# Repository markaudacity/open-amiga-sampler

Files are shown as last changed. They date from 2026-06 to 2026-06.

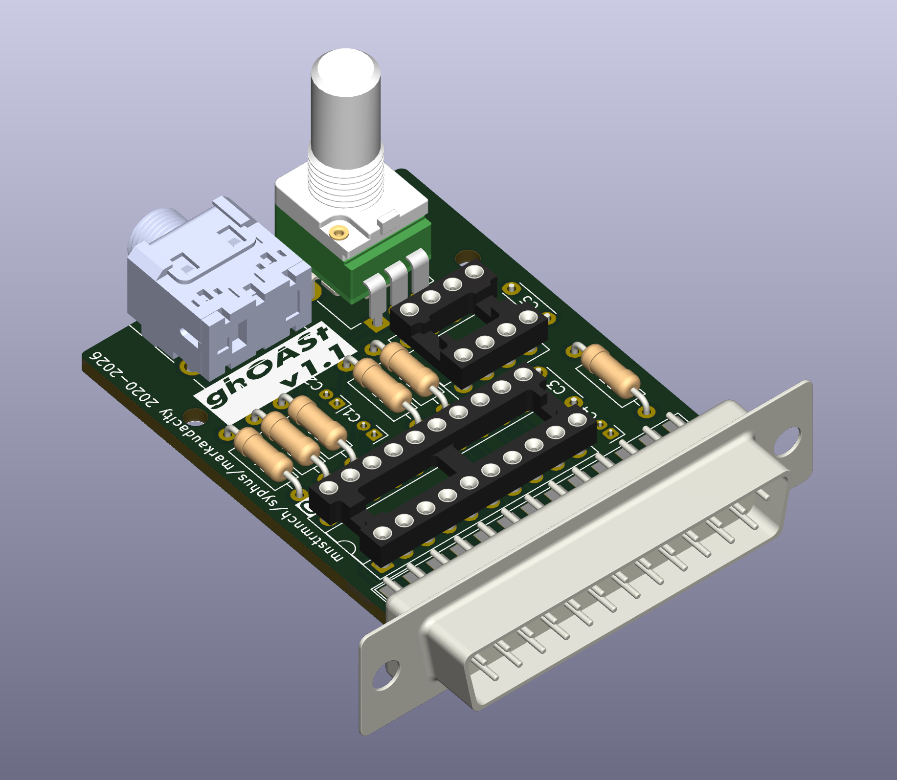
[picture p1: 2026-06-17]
img/ghOASt_v1.1_ortho.png

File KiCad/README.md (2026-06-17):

# OPEN AMIGA SAMPLER

## Overview

Here you can find the schematic and a PCB layout for Open Amiga Sampler in KiCAD format. Additionally, the schematic is available as a PDF.
The design consists of an inverting opamp circuit with variable gain which feeds an ADC. The DB25's strobe pin is connected to the ADC and initiates a conversion when it goes low. The ADC's outputs are connected to the data pins of a DB25 connector, which also provides power and ground. 

## BOM

* 1x Maxim ADC0820CCN+
* 1x Microchip MCP6002-I/P
* 1x DB25 plug connector
* 2x RCA receptacles
* 1x 330ohm resistor
* 5x 1kohm resistors
* 1x 10kohm exponential potentimeter
* 1x 47uf capacitor
* 2x 10uf capacitors
* 2x 0.1uf capacitors

### Substitutions

The 10kohm potentiometer will give between 1x and 10x gain. A larger potentiometer can be substituted to enable a large maxium gain. The RCA receptacles can be replaced by a stereo jack receptacle if preferred. It is likely that both ICs could be substituted for similar chips with identical pinouts, but these are the models that we have tested and confirmed to work.

## Soldering

All components are through-hole and should be relatively easy to solder even for a novice. Some components can be soldered to the back of the board and folded down to make the overall unit slimmer. One possible configuration is to solder C1, C2, C3 and C5 to the back of the board, and fold C4 down onto the front footprint of C3. We recommend soldering the DB25 connector first, followed by the passive components and leads, and finally the ICs. This reduces the chance of damaging the ICs with excessive heat.

## Case

We are working on a compact 3D printed case in an approriate form factor for all Amiga computers. You may be able to find an appropriate enclosure to build the device into, but if you intend to plug the device directly into your Amiga you will need to make sure that ports adjacent to the parallel port will not be impeded.

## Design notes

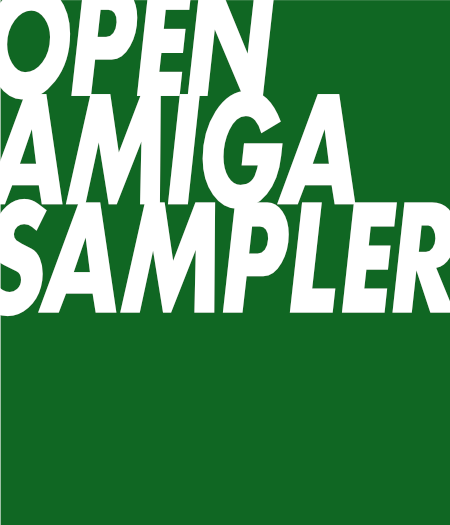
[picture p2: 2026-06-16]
graphics/open amiga sampler interrupted styletext.png

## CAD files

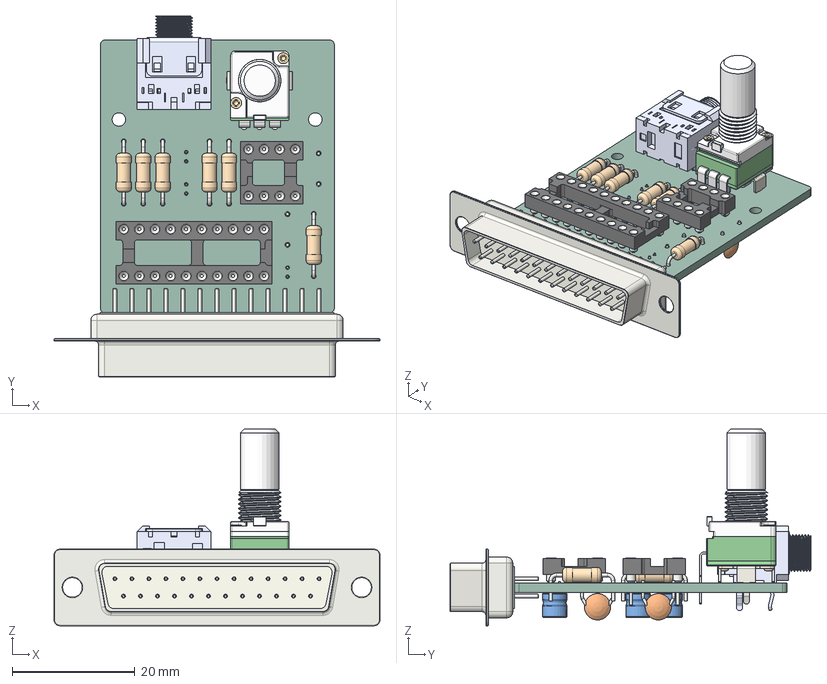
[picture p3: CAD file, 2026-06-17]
KiCad/ghOASt v1.1.step
53.1 x 58.7 x 32.0 mm
DSUB-25_Male_Vertical_P2.77x2.84mm
DIP_20_W762mm_Socket
R_Axial_DIN0207_L63mm_D25mm_P1016mm_Horizontal x 6
DIP_8_W762mm_Socket
CUI_DEVICES_SJ1-3543
RD901F-40-15R1 v9
CP_Radial_D40mm_P150mm x 3
C_Disc_D43mm_W19mm_P500mm x 2
open-amiga-sampler_PCB

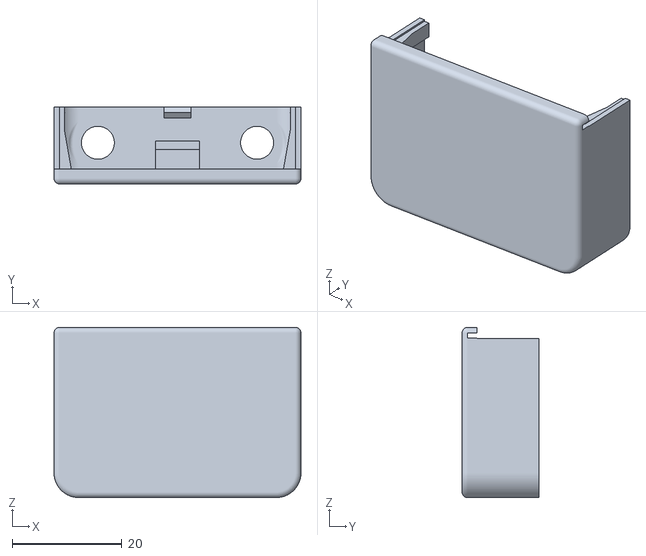
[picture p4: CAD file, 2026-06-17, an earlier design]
legacy/smd-fork/case models/OAS-lower-shell.stl
45.0 x 14.0 x 31.0

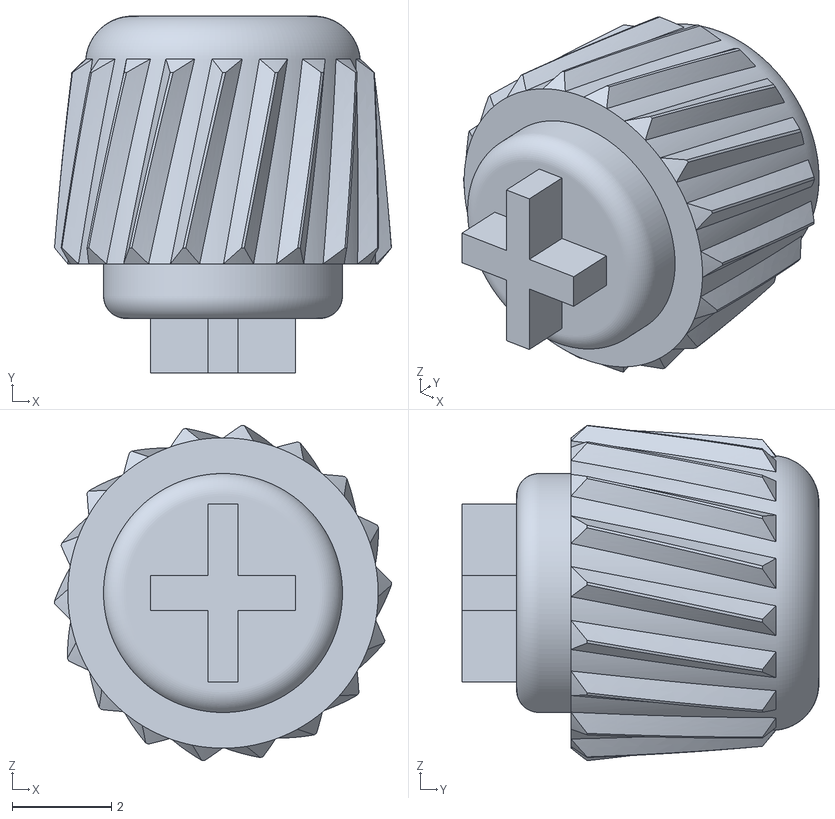
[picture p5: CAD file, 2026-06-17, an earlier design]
legacy/smd-fork/case models/OAS-trimmer-knob.stl
6.80 x 7.20 x 6.77

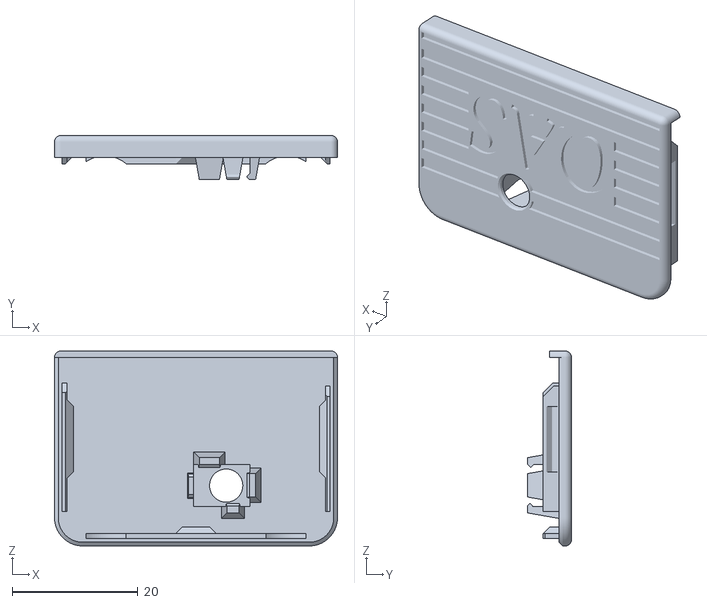
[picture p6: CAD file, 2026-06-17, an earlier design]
legacy/smd-fork/case models/OAS-Top shell.stl
45.0 x 7.00 x 31.0

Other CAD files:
graphics/open amiga sampler interrupted styletext.dxf
graphics/open amiga sampler interrupted styletext.dwg

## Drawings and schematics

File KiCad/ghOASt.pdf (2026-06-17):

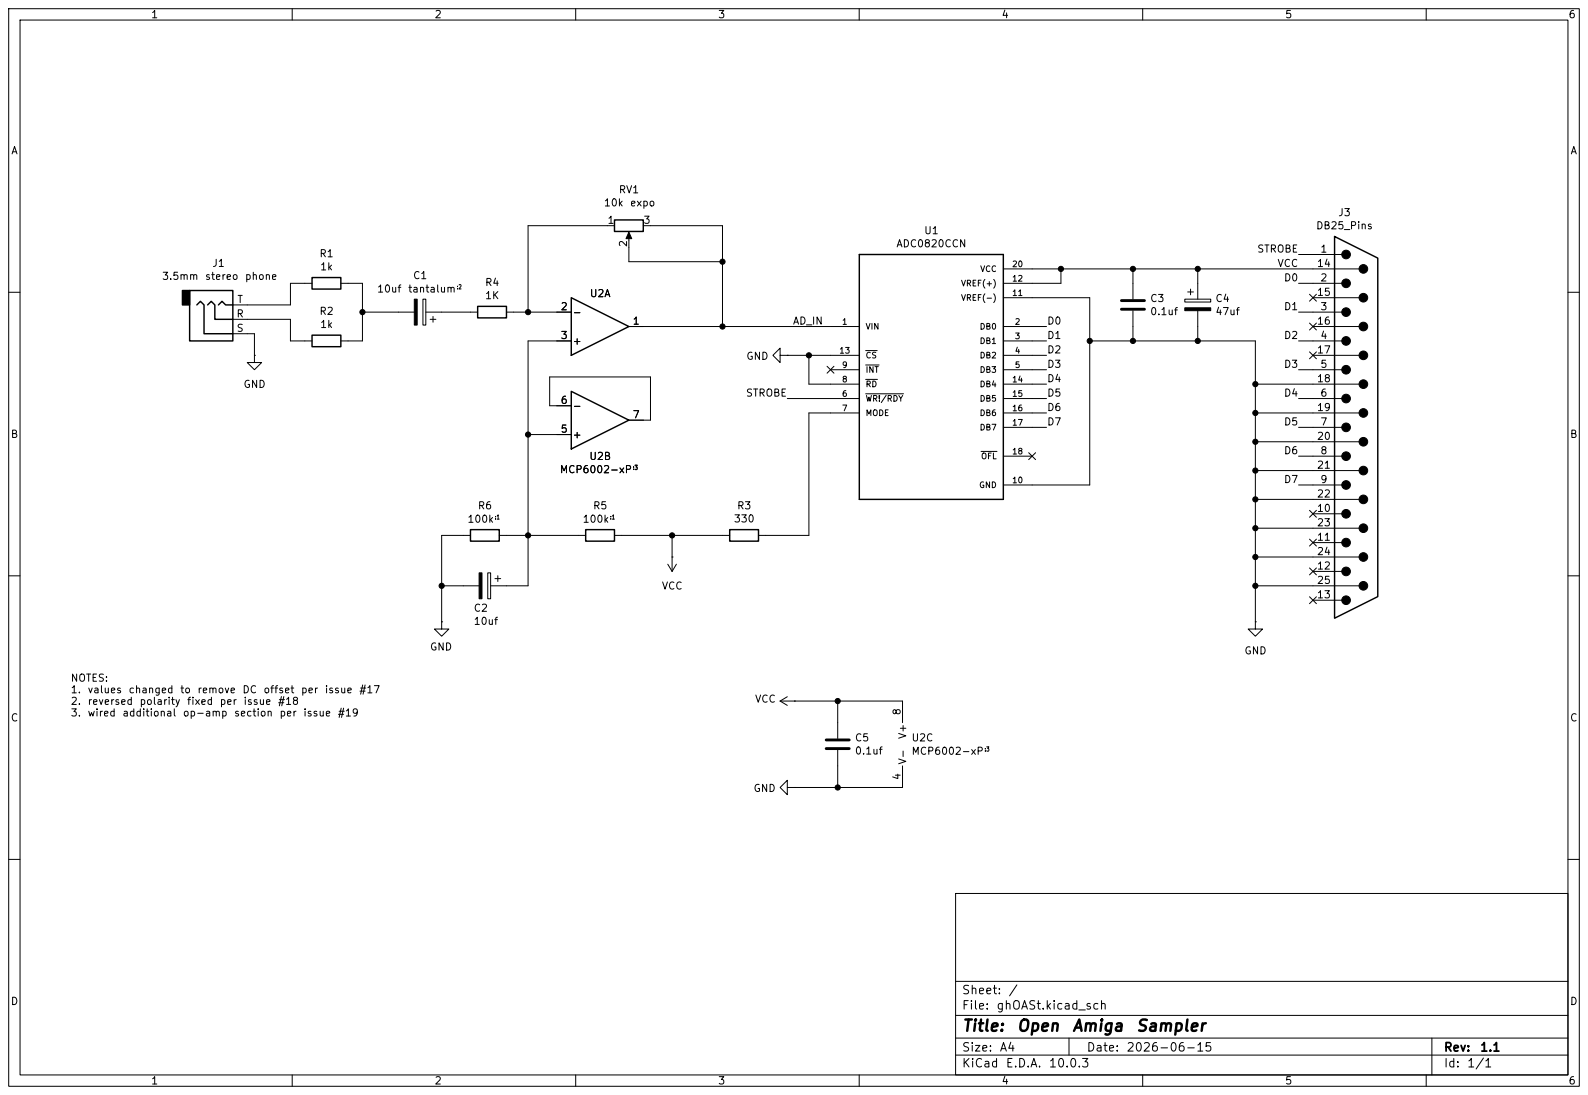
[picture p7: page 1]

STROBED0 NOTES: 1. values changed to remove DC offset per issue #17

2. reversed polarity fixed per issue #18

Sheet: /
File: ghOASt.kicad_sch
Title: Open Amiga Sampler

Size: A4 | Rev: 1.1
KiCad E.D.A. 10.0.3 | Id: 1/1

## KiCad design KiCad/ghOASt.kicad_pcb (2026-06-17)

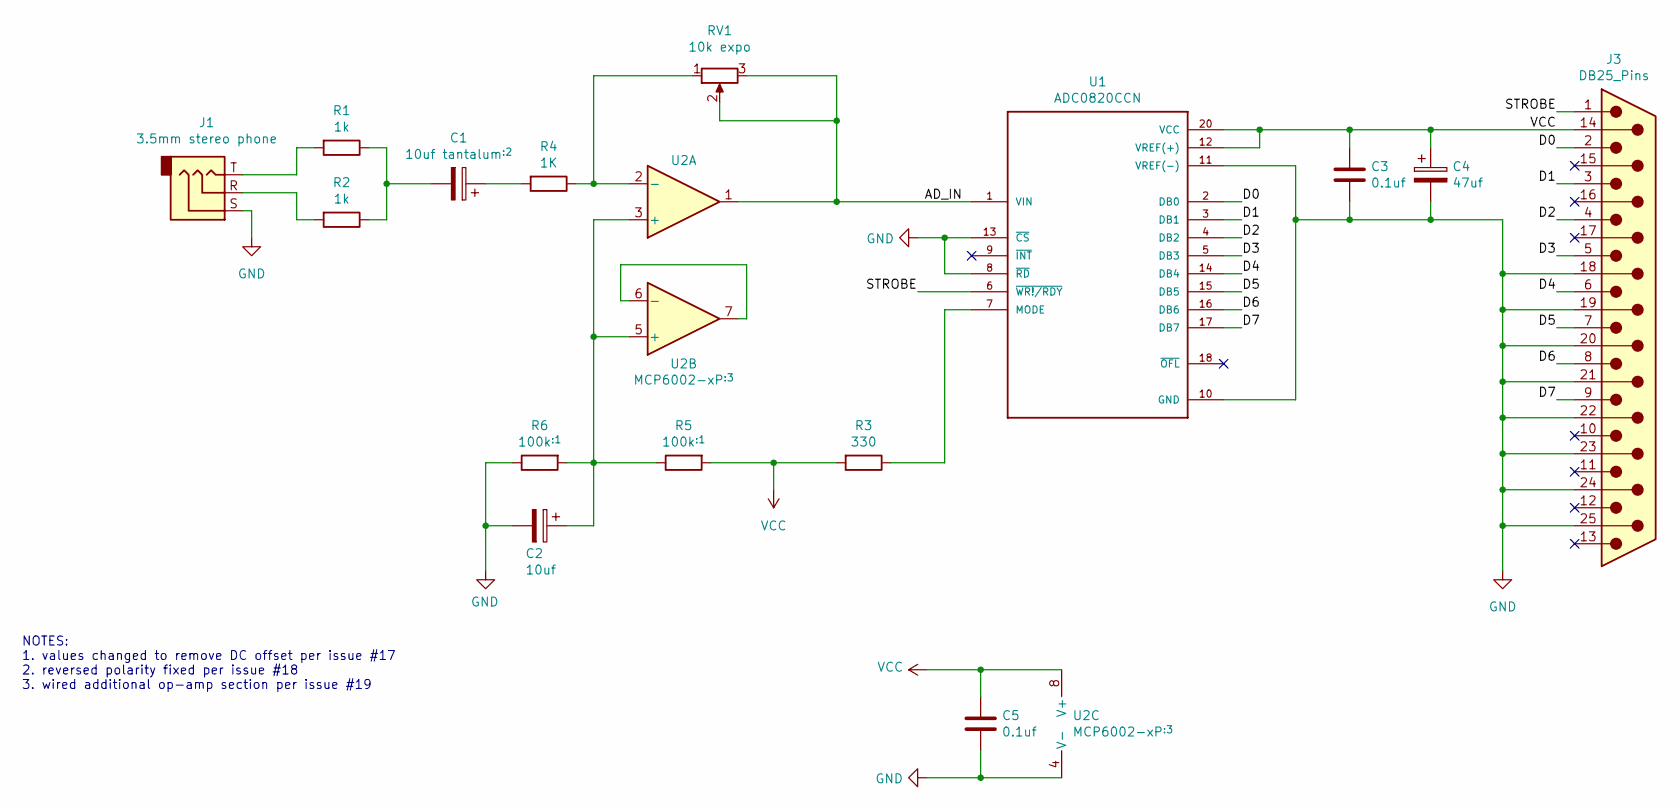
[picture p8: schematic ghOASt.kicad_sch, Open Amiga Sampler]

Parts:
C1: 10uf tantalum^{:2}; CP_Radial_D4.0mm_P1.50mm
C2: 10uf; CP_Radial_D4.0mm_P1.50mm
C3, C5: 0.1uf; C_Disc_D4.3mm_W1.9mm_P5.00mm
C4: 47uf; CP_Radial_D4.0mm_P1.50mm
J1: 3.5mm stereo phone; Jack_3.5mm_CUI_SJ1-3543
J3: DB25_Pins; DSUB-25_Male_EdgeMount_P2.77mm
R1, R2: 1k; R_Axial_DIN0207_L6.3mm_D2.5mm_P10.16mm_Horizontal
R3: 330; R_Axial_DIN0207_L6.3mm_D2.5mm_P10.16mm_Horizontal
R4: 1K; R_Axial_DIN0207_L6.3mm_D2.5mm_P10.16mm_Horizontal
R5, R6: 100k^{:1}; R_Axial_DIN0207_L6.3mm_D2.5mm_P10.16mm_Horizontal
RV1: 10k expo; Potentiometer_Alpha_RD901F-40-00D_Single_Vertical
U1: ADC0820CCN; DIP-20_W7.62mm_Socket
U2: MCP6002-xP^{:3}; DIP-8_W7.62mm_Socket

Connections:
/AD_IN: RV1.2, RV1.3, U1.1 (VIN), U2.1
/D0: J3.2, U1.2 (DB0)
/D1: J3.3, U1.3 (DB1)
/D2: J3.4, U1.4 (DB2)
/D3: J3.5, U1.5 (DB3)
/D4: J3.6, U1.14 (DB4)
/D5: J3.7, U1.15 (DB5)
/D6: J3.8, U1.16 (DB6)
/D7: J3.9, U1.17 (DB7)
/STROBE: J3.1, U1.6 (~WR!/RDY)
GND: C2.2, C3.2, C4.2, C5.2, J1.S, J3.18, J3.19, J3.20, J3.21, J3.22, J3.23, J3.24, J3.25, R6.1, U1.8 (~RD), U1.10 (GND), U1.11 (VREF(-)), U1.13 (~CS), U2.4 (V-)
unnamed: C1.1, R4.2
unnamed: C1.2, R1.1, R2.1
unnamed: J1.R, R2.2
unnamed: J1.T, R1.2
unnamed: R3.1, U1.7 (MODE)
unnamed: C2.1, R5.1, R6.2, U2.3 (+), U2.5 (+)
unnamed: R4.1, RV1.1, U2.2 (-)
unnamed: U2.6 (-), U2.7
VCC: C3.1, C4.1, C5.1, J3.14, R3.2, R5.2, U1.12 (VREF(+)), U1.20 (VCC), U2.8 (V+)

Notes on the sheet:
NOTES: 1. values changed to remove DC offset per issue #17 2. reversed polarity fixed per issue #18 3. wired additional op-amp section per issue #19

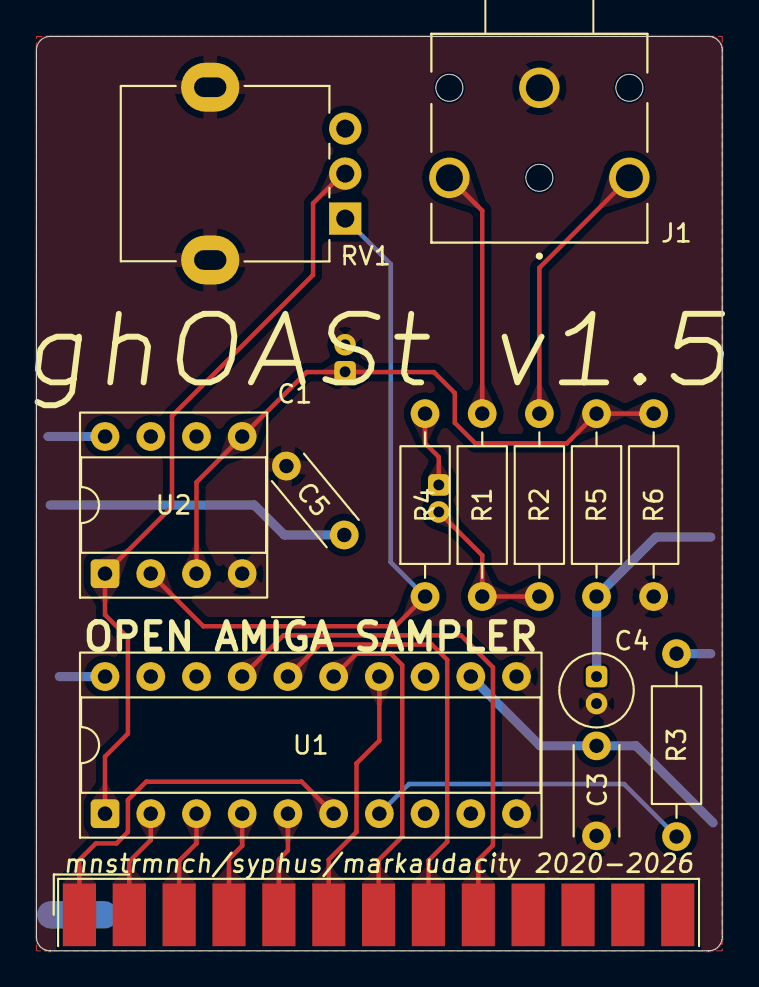
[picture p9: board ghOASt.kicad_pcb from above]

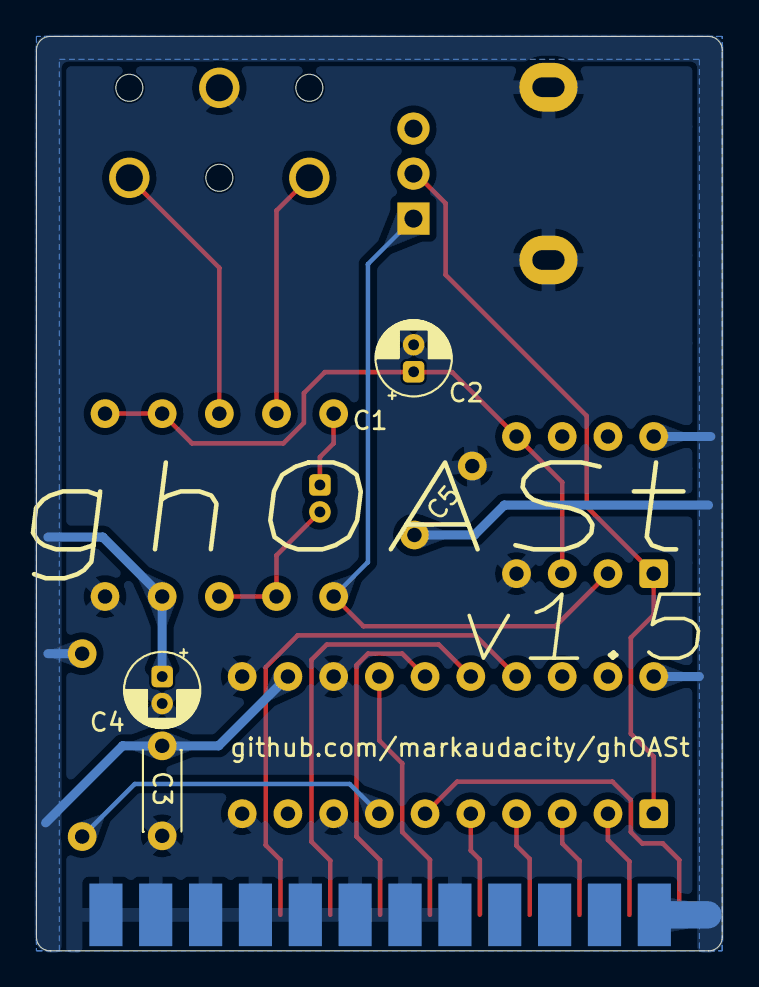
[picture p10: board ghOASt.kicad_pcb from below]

Board: 2 copper layers, 38.1 x 50.8 mm, 16 parts (5 on the bottom side), 20 nets.

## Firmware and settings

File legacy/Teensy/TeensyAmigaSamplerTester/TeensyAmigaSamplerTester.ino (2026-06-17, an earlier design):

/*
   http://github.com/echolevel/open-amiga-sampler
   
   Tested on Teensy 3.5 with microSD card
   USB type: 'Serial'
   CPU speed: '120Mhz'
   
   Everything else Arduino/Teensy default.
   
   This Teensy-based sampler tester mimics the behaviour of an Amiga parallel port during a 
   sampling operation (bytes are read and a a STROBE signal is emitted, as per the Amiga CIA 
   chip's behaviour). This is to reduce the risk of frying real Amigas' CIA chips during testing. 

   8 digital input pins connect straight to a DB25 connector's data pins, while three digital output pins 
   are converted from 3.3v to 5v before being connected to the DB25's STROBE, SELECT and PAPER_OUT pins.
   The DB25 connector also takes 5v directly from the Teensy's USB 5v input (this may need to be soldered 
   to the Teensy for a decent contact). See the OAS github for full docs/wiring diagrams.
   
   To convert raw: sox -t raw -r 16574.2757 -b 8 -c 1 -L -e signed-integer .\audio.raw .\audio.wav
   This tells sox to assume a samplerate that matches Protracker note C-3, and is calculated by 
   working out a PAL Amiga's clock speed divided by the note period from a LUT (214, in this case).
   -c is channel count 
   -L is endianness (irrelevant with 8bit values)
   -e is encoding, signed int

   Notes: the STROBE is sent by the Amiga's CIA chip at a fixed rate - ie the sample rate - after every
   data byte is read. On an Amiga this process is discrete/automatic, so from a programmer's perspective 
   the speed at which bytes are read (usually with an interrupt request - $DFF01E) is the desired sample 
   rate. But here we're doing it manually, sorta back to front. 

   The rate of that custom interrupt on the Amiga isn't actually the sample rate, it's the note period - 
   in other words, a value from a lookup table by which you divide the Amiga's PAL or NTSC clock frequency
   to get a sample rate. 

   5512.5 samplerate with 5 and 40 delays is roughly F-1 note

   Amiga clock: 3546895   
   B-3 period: 113
   F-1 period: 640

   B-3 samplerate: 31388.45
*/

#include <SPI.h>
#include <SD.h>
#include <SD_t3.h>

int strobePin = 9;
int paperPin = 10;
int selectPin = 11;
int speakerPin = 35;
int paperState = HIGH;
int selectState = LOW;

uint8_t inChar = 0;
int aBufferSize = 128000;
int bufferCount = 0;
int buffersWritten = 0;
uint8_t audioBuffer[128000];
const int chipSelect = BUILTIN_SDCARD;

// the setup routine runs once when you press reset:
void setup() {
    
  // 8 contiguous bits on Teensy 3.5:
  /*
     D0 2
     D1 14
     D2 7
     D3 8
     D4 6
     D5 20
     D6 21
     D7 5
  */
  pinMode(2, INPUT_PULLUP);
  pinMode(14, INPUT_PULLUP);
  pinMode(7, INPUT_PULLUP);
  pinMode(8, INPUT_PULLUP);
  pinMode(6, INPUT_PULLUP);
  pinMode(20, INPUT_PULLUP);
  pinMode(21, INPUT_PULLUP);
  pinMode(5, INPUT_PULLUP);  

  // These 3 control pins' logic output has to be converted to 5v 
  pinMode(strobePin, OUTPUT);
  // selectPin and paperPin control switching between left and right - tbc, but I think 
  // you alternate one high vs one low per read
  pinMode(selectPin, OUTPUT);
  pinMode(paperPin, OUTPUT);
  pinMode(speakerPin, OUTPUT);

  Serial.begin(9600);
  while (!Serial) {
    ; //wait for serial port to connect
  }


  Serial.print("Initialising SD card...");

  if (!SD.begin(chipSelect)) {
    Serial.println("Card failed, or not present");
    return;
  }
  Serial.println("card initialised");
  
}



// the loop routine runs over and over again forever:
void loop() {

  /*
   * In case you need to test each individual bit (can help diagnose continuity problems)
   * 
  String out;
  for (int i = 0; i < 8; i++) {
    out += digitalRead(i);
  }
  Serial.println(out);*/
  

  inChar = GPIOD_PDIR & 0xFF;


  if (bufferCount < aBufferSize) {

    

    audioBuffer[bufferCount] = inChar;

  } else {

    bufferCount = 0;
    
    File dataFile = SD.open("audio.raw", FILE_WRITE);
    
    if (buffersWritten == 0) {
      
      /* 
       * Unclear whether file seeking/overwriting works, so it's probably best to delete audio.raw from 
       * the SD card and touch a new one before each test (otherwise you might end up with multiple test
       * sessions being appended to the same file).
       * Linux/MacOS: rm audio.raw && touch audio.raw
       * Windows PowerShell: delete audio.raw; New-Item audio.raw -ItemType file
       */
       
      dataFile.seek(0);
      
    }
    
    if (dataFile) {
      Serial.println("Writing buffer to file");
      for (int i = 0; i < aBufferSize; i++) {
        
        dataFile.write( (int8_t)((int16_t) audioBuffer[i] - 128) );
        
      }
      
      dataFile.close();
      Serial.println("Done");
      buffersWritten++;
      
    } else {
      
      Serial.println("Error opening audio.raw");
      
    }


  }

  bufferCount++;  

  // For mono, don't switch these per cycle
  /*
  int tmp = paperState;
  paperState = selectState;
  selectState = tmp;
  */
  
  digitalWrite(selectPin, selectState); 
  digitalWrite(paperPin, paperState);

  digitalWrite(strobePin, LOW);
  delayMicroseconds(5);

  digitalWrite(strobePin, HIGH);
  delayMicroseconds(40);
  

}

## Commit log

2026-06-16 streamlined schematic, added mods up to 1.1
    [open-amiga-sampler.kicad_sch]
2026-06-16 major update to PCB
    removed unnecessary traces and vias, re-routed everything, added footprints for gain pot and 3.5mm phone jack soldered direct to board
    Lots of KiCad project cleanup: added netclasses, adjusted design rules, changed global labels to local (since the schematic only has one page) and unified the schematic so it is no longer in several separate pieces
    [open amiga sampler interrupted styletext.dwg, open amiga sampler interrupted styletext.dxf, open-amiga-sampler.kicad_pcb]
2026-06-16 tweaks, edits, embedded models
    [open-amiga-sampler.kicad_pcb, open-amiga-sampler.kicad_sch]
2026-06-17 fixing some sync oopsies
    [ghOASt v1.1.step, open-amiga-sampler.kicad_pcb]
